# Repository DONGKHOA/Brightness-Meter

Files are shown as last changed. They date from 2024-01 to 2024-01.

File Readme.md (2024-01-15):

# BRIGHTNESS METER
## Yêu cầu hệ thống
- Thiết kế máy đo độ rọi ánh sáng sử dụng LDR: có 2 thang đo
  - Thang 1: tầm đo 10-100lux, độ phân giải 1lux
  - Thang 2: tầm đo 10-1000lux, độ phân giải 10lux
  - Màn hình hiển thị LCD giá trị đo được, có nút nhấn để thay đổi giữa 2 thang đo
  - Mạch cho phép cài đặt giá trị ngưỡng độ rọi thông qua LCD và nút nhấn. Nếu độ rọi đặt vào máy đo lớn hơn giá trị cài đặt, báo đỏ LED.

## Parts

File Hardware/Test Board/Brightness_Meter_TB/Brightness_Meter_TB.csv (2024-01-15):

Reference | Value | URL | Qty
-5V_LED1 | BLUE | https://www.thegioiic.com/led-xanh-duong-0805-dan-smd-trong-suot-harvatek | 1
3.3V1 | RED | https://www.thegioiic.com/led-xanh-duong-0805-dan-smd-trong-suot-harvatek | 1
BZ1 | Buzzer |  | 1
C1 | 22uF/25V | https://www.thegioiic.com/tu-nhom-smd-22uf-25v-6-3x5-4mm | 1
C2, C3 | 10uF/16V | https://www.thegioiic.com/tu-tantalum-10uf-16v-1206-taja106k016rnj | 2
C4, C11-C14, C16, C17, C19, C20, C22-C27 | 100nF/50V | https://www.thegioiic.com/tu-gom-0805-100nf-0-1uf-50v | 15
C5-C9, C18, C21 | 10uF/6.3V | https://www.thegioiic.com/tu-gom-0805-10uf-6-3v | 7
C10 | 10pF/50V | https://www.thegioiic.com/tu-gom-0805-10pf-50v | 1
C15 | 1uF/16V | https://www.thegioiic.com/tu-gom-0805-1uf-16v | 1
D1, D3 | SS34 | https://www.thegioiic.com/ss34-sma-diode-schottky-3a | 2
D2 | ZMM3V3 | https://www.thegioiic.com/zmm3v3-diode-zener-3-3v-500mw-smd | 1
D4 | ZMM5V1 | https://www.thegioiic.com/zmm5v1-diode-zener-5-1v-500mw-smd | 1
F1 | Fuse_Small |  | 1
J1 | JACK-DC | https://www.thegioiic.com/dc050-dau-noi-nguon-dc-cai-5521-dan-smd-kim-2-1mm | 1
Q1 | MMBT2222A |  | 1
Q2-Q5 | BSN20 | https://www.thegioiic.com/bsn20bkr-mosfet-kenh-n-50v-173ma-sot-23 | 4
R1, R2 | 4.7k/1% | https://www.thegioiic.com/dien-tro-4-7-kohm-0805-1- | 2
R3, R5-R8 | R_Small_US |  | 5
R4 | EVM-3ESX50B14 |  | 1
R9, R13 | EVM-3E |  | 2
R10, R11 | 0/1% | https://www.thegioiic.com/dien-tro-0-ohm-0805-1- | 2
R12 | GL5528 | https://www.thegioiic.com/gl5528-quang-tro-5mm | 1
R14 | 220/1% | https://www.thegioiic.com/dien-tro-220-ohm-0805-1- | 1
R15-R20, R23-R30 | 10k/1% | https://www.thegioiic.com/dien-tro-10-kohm-0805-1- | 14
R21, R22 | 1k/1% | https://www.thegioiic.com/dien-tro-1-kohm-0805-1- | 2
SW1 | UP | https://www.thegioiic.com/b3f-4055-nut-nhan-12x12mm-cao-7-3mm-4-chan-xuyen-lo-omron | 1
SW2 | DOWN | https://www.thegioiic.com/b3f-4055-nut-nhan-12x12mm-cao-7-3mm-4-chan-xuyen-lo-omron | 1
SW3 | LEFT | https://www.thegioiic.com/b3f-4055-nut-nhan-12x12mm-cao-7-3mm-4-chan-xuyen-lo-omron | 1
SW4 | RIGHT | https://www.thegioiic.com/b3f-4055-nut-nhan-12x12mm-cao-7-3mm-4-chan-xuyen-lo-omron | 1
SW5 | SET | https://www.thegioiic.com/b3f-4055-nut-nhan-12x12mm-cao-7-3mm-4-chan-xuyen-lo-omron | 1
SW6 | MODE | https://www.thegioiic.com/b3f-4055-nut-nhan-12x12mm-cao-7-3mm-4-chan-xuyen-lo-omron | 1
U1 | ICL7662CPA | https://www.thegioiic.com/icl7662cba | 1
U2 | STM32F103C8T6 |  | 1
U3 | MCP6002 | https://www.thegioiic.com/mcp6002-i-sn-ic-opamp-general-purpose-amplifier-2-circuit-1mhz-8-soic | 1
U4 | INA128 | https://tme.vn/Product.aspx?id=1612#page=pro_info | 1
U5 | HX710B | https://www.thegioiic.com/hx710b-ic-adc-24-bit-sop-8 | 1
U6 | SSD1306 | https://www.thegioiic.com/lcd-oled-ssd1306-0-96inch-128x64-chu-trang-4-chan-giao-tiep-iic | 1
Vin_LED1 | BLUE | https://www.thegioiic.com/led-xanh-duong-0805-dan-smd-trong-suot-harvatek | 1

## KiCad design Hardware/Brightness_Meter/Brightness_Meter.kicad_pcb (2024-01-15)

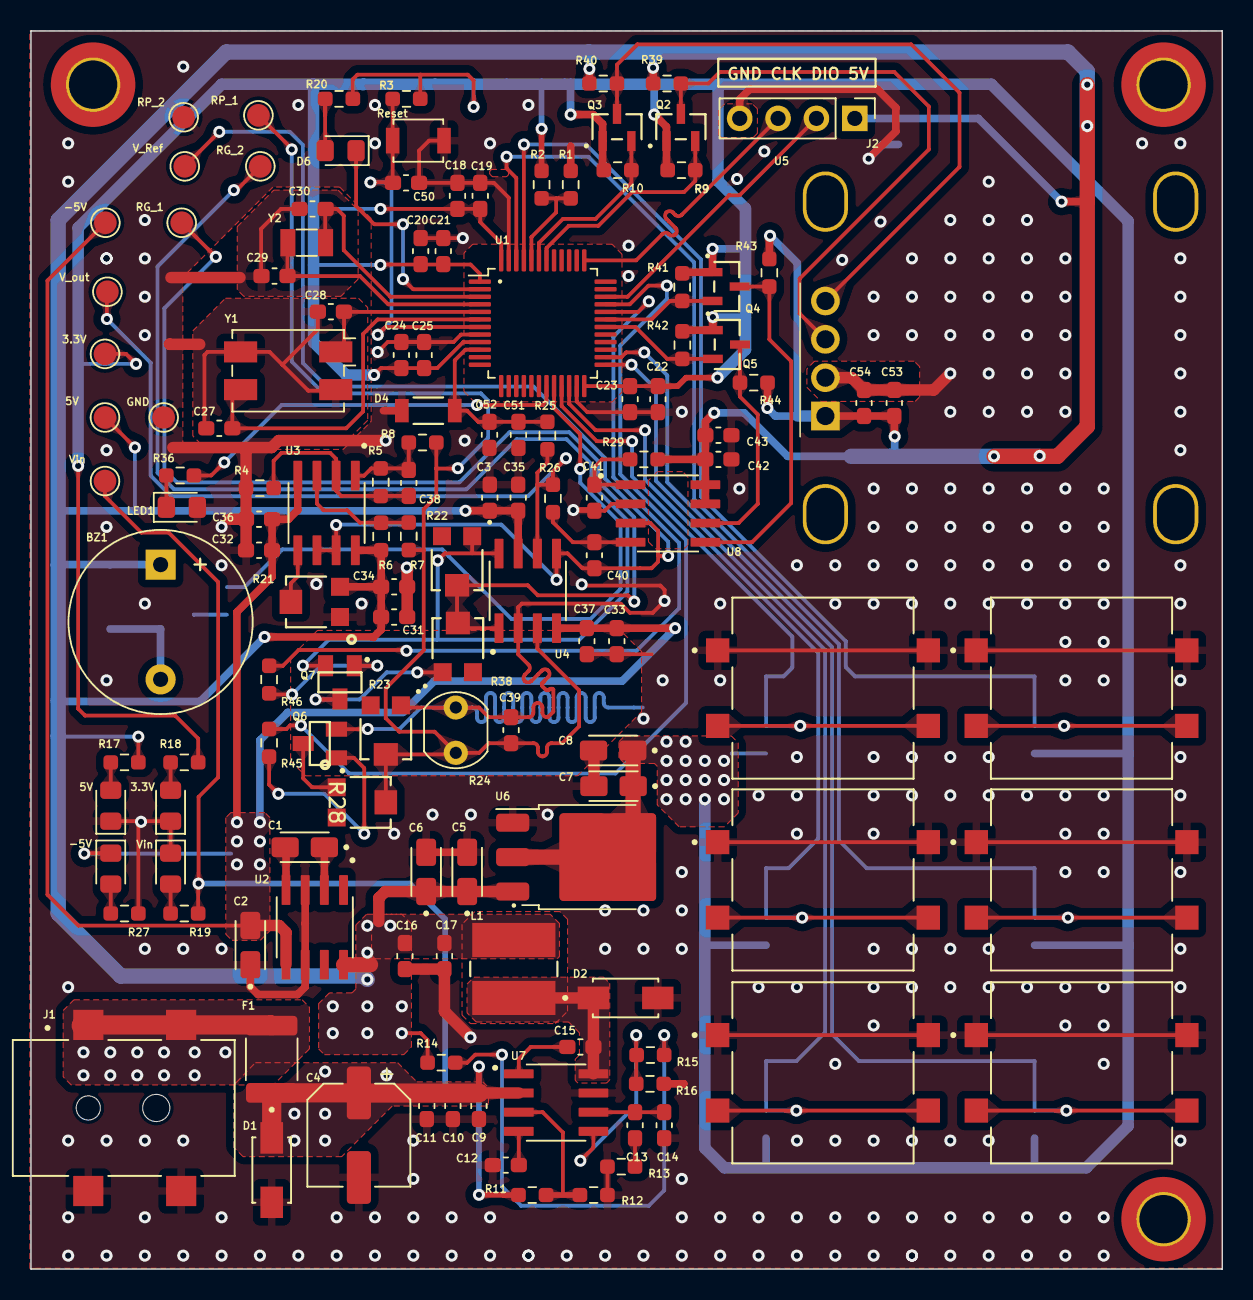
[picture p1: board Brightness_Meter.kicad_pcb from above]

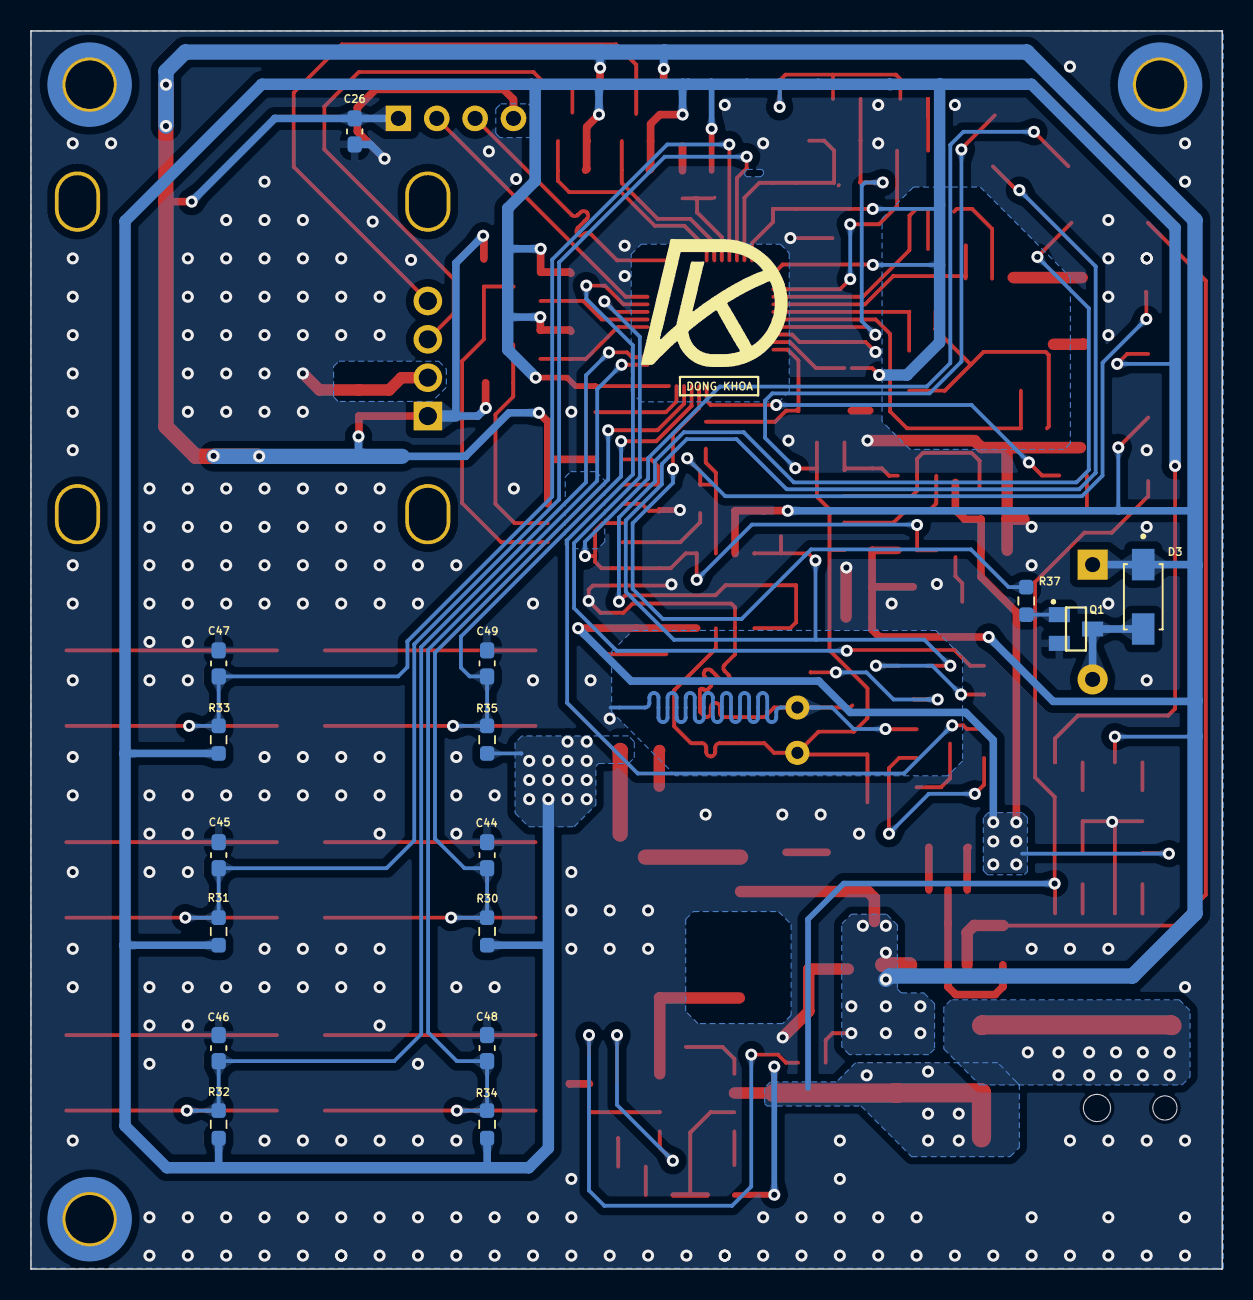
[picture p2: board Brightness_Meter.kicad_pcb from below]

Board: 2 copper layers, 78.9 x 82.0 mm, 153 parts (16 on the bottom side), 67 nets.

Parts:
3.3V: 3.3V; TestPoint_Pad_D1.5mm
3.3V#2, 5V#2: BLUE; LED_0805_2012Metric_Pad1.15x1.40mm_HandSolder
5V: 5V; TestPoint_Pad_D1.5mm
-5V: -5V; TestPoint_Pad_D1.5mm
-5V#2: BLUE; LED_0805_2012Metric_Pad1.15x1.40mm_HandSolder
BZ1: Buzzer; Buzzer_12x9.5RM7.6
C1, C2, C6, C7: 10uF/16V; CAPMP3216X180N
C3, C26, C31, C32, C33, C51: 10uF/16V; C_0603_1608Metric_Pad1.08x0.95mm_HandSolder
C4: 22uF/25V; CP_Elec_6.3x5.4
C5, C8: 1uF/25V; CAPMP3216X180N
C9, C10: 4.7uF/25V; C_0603_1608Metric_Pad1.08x0.95mm_HandSolder
C11, C12, C25: 10nF/50V; C_0603_1608Metric_Pad1.08x0.95mm_HandSolder
C13: 1nF/50V; C_0603_1608Metric_Pad1.08x0.95mm_HandSolder
C14: 47pF/50V; C_0603_1608Metric_Pad1.08x0.95mm_HandSolder
C15: 0.1uF/16V; C_0603_1608Metric_Pad1.08x0.95mm_HandSolder
C16, C17: 47uF/6.3V; C_0603_1608Metric_Pad1.08x0.95mm_HandSolder
C18, C20, C22: 4.7uF/10V; C_0603_1608Metric_Pad1.08x0.95mm_HandSolder
C19, C21, C23, C34, C35, C36, C37, C44, C45, C46, C47, C48, C49, C50, C52: 100nF/16V; C_0603_1608Metric_Pad1.08x0.95mm_HandSolder
C24, C39: 1uF/16V; C_0603_1608Metric_Pad1.08x0.95mm_HandSolder
C27, C28, C29, C30: 20pF/50V; C_0603_1608Metric_Pad1.08x0.95mm_HandSolder
C38: 10pF/50V; C_0603_1608Metric_Pad1.08x0.95mm_HandSolder
C40, C41, C43, C54: 100nF/50V; C_0603_1608Metric_Pad1.08x0.95mm_HandSolder
C42, C53: 10uF/6.3V; C_0603_1608Metric_Pad1.08x0.95mm_HandSolder
D1, D2, D3: SS34; DIOM4325X250N
D4: ZMM3V3; ZDO_ZMM_3p5x1p45_STM
D6: Led_test; LED_0805_2012Metric_Pad1.15x1.40mm_HandSolder
DOWN1: DOWN; SW_TL3300CF260Q
F1: Fuse_Small; Fuse_1812_4532Metric_Pad1.30x3.40mm_HandSolder
GND: GND; TestPoint_Pad_D1.5mm
H1, H2, H3: MountingHole; MountingHole_3.2mm_M3_DIN965_Pad_TopBottom
J1: JACK-DC; SPARKFUN_PRT-12748
J2: Load Program; PinHeader_1x04_P2.54mm_Vertical
L1: 6.8uH/2.2A; IND_SDE0604A_5P8X5P2X4P5_BRN
LED1: RED; LED_0805_2012Metric_Pad1.15x1.40mm_HandSolder
LEFT1: LEFT; SW_TL3300CF260Q
MODE1: MODE; SW_TL3300CF260Q
Q1, Q6, Q7: MMBT2222A; SOT23
Q2, Q3, Q4, Q5: BSN20; SOT23_NEX
R1, R2, R25, R26: 0/1%; R_0603_1608Metric_Pad0.98x0.95mm_HandSolder
R3, R9, R10, R16, R30, R31, R32, R33, R34, R35, R39, R40, R41, R42, R43, R44: 10k/1%; R_0603_1608Metric_Pad0.98x0.95mm_HandSolder
R4, R5, R6, R7, R8: R_Small_US; R_0603_1608Metric_Pad0.98x0.95mm_HandSolder
R11: 330k/1%; R_0603_1608Metric_Pad0.98x0.95mm_HandSolder
R12: 47k/1%; R_0603_1608Metric_Pad0.98x0.95mm_HandSolder
R13: 30k/1%; R_0603_1608Metric_Pad0.98x0.95mm_HandSolder
R14: 2.49k/1%; R_0603_1608Metric_Pad0.98x0.95mm_HandSolder
R15: 49.9k/1%; R_0603_1608Metric_Pad0.98x0.95mm_HandSolder
R17, R18, R20, R36, R37, R45, R46: 1k/1%; R_0603_1608Metric_Pad0.98x0.95mm_HandSolder
R19, R27: 4.7k/1%; R_0603_1608Metric_Pad0.98x0.95mm_HandSolder
R21: EVM-3ESX50B14; EVM-3ESX50B14_PAN
R22, R23, R28, R38: EVM-3E; EVM-3ESX50B14_PAN
R24: GL5528; R_LDR_5.0x4.1mm_P3mm_Vertical
R29: 220/1%; R_0603_1608Metric_Pad0.98x0.95mm_HandSolder
RG_1, RG_2: RG; TestPoint_Pad_D1.5mm
RIGHT1: RIGHT; SW_TL3300CF260Q
RP_1, RP_2: RP; TestPoint_Pad_D1.5mm
Reset: SW_Push; SW_SPST_B3U-1000P
SET1: SET; SW_TL3300CF260Q
U1: STM32F030C8Tx; LQFP-48_7x7mm_P0.5mm
U2: ICL7662CPA; SOIC127P600X175-8N
U3: MCP6002; SOIC127P599X173-8N
U4: INA128; SOIC127P599X175-8N
U5: SSD1306
U6: LM1117DT-3.3; TO-252-3_TabPin2
U7: TPS54331D; SOIC127P599X175-8N
U8: HX710B
UP1: UP; SW_TL3300CF260Q
V_Ref: V_Ref; TestPoint_Pad_D1.5mm
V_out: V_out; TestPoint_Pad_D1.5mm
Vin: BLUE; LED_0805_2012Metric_Pad1.15x1.40mm_HandSolder
Vin#2: Vin; TestPoint_Pad_D1.5mm
Y1: 8MHz; Crystal_SMD_EuroQuartz_MQ-4Pin_7.0x5.0mm
Y2: 32.768KHz; Crystal_SMD_3215-2Pin_3.2x1.5mm

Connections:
+3.3V: 3.3V.1, C7.1, C8.1, C18.1, C19.1, C20.1, C21.1, C22.1, C23.1, C24.1, C25.1, Q2.1 (G), Q3.1 (G), Q4.1 (G), Q5.1 (G), R2.1, R3.1, R9.1, R10.1, R18.1, R20.1, R30.2, R31.2, R32.2, R33.2, R34.2, R35.2, R41.1, R42.1, U1.1 (VDD), U1.9 (VDDA), U1.24 (VDD), U1.48 (VDD), U6.2 (VO)
+5V: 5V.1, BZ1.1 (-), C3.1, C5.1, C6.1, C16.1, C17.1, C26.1, C31.1, C34.1, C35.1, C42.1, C43.1, C53.1, C54.1, D3.C, J2.1, L1.1, R6.2, R14.1, R17.1, R21.3, R29.2, R39.1, R40.1, R43.1, R44.1, U2.8 (V+), U3.8 (VDD), U4.7 (V+), U5.1 (vcc), U6.3 (VI), U8.7 (DVDD), U8.8 (AVDD)
-5V: -5V.1, -5V#2.1 (K), C2.2, C32.2, C33.2, C36.2, C37.2, U2.5 (VOUT), U3.4 (VSS), U4.4 (V-)
/MCU/BOOT0: R1.1, R2.2, U1.44 (BOOT0)
/MCU/LED_TEST: D6.1 (K), U1.2 (PC13)
/MCU/OSC32_IN: C30.1, U1.3 (PC14), Y2.1
/MCU/OSC32_OUT: C29.1, U1.4 (PC15), Y2.2
/MCU/OSC_IN: C28.1, U1.5 (PF0), Y1.1
/MCU/OSC_OUT: C27.1, U1.6 (PF1), Y1.3
/MCU/RESET: C50.2, R3.2, Reset.2, U1.7 (NRST)
/MCU/SWCLK: J2.3, U1.37 (PA14)
/MCU/SWDIO: J2.2, U1.34 (PA13)
/Power/Vin: C4.1, C9.1, C10.1, C11.1, D1.C, F1.2, R11.1, R19.1, U7.2 (VIN), Vin#2.1
/measure/CURRENT_SRC: C39.2, R7.1, R8.2, R23.2, R24.1, R28.2, RP_1.1, U4.3 (+)
/measure/vout: R25.2, R26.1, U4.6, V_out.1
ADC_CLK: Q4.2 (S), R41.2, U1.31 (PA10)
ADC_DATA: Q5.2 (S), R42.2, U1.30 (PA9)
ADC_HX71OB: C40.2, R26.2, U8.4 (INP)
ADC_INO: C51.1, C52.1, D4.1, R25.1, U1.10 (PA0)
BUZZER: R37.1, U1.20 (PB2)
CHANGE_GAIN: R46.2, U1.32 (PA11)
CHANGE_RESISTOR: R45.2, U1.33 (PA12)
CLK_HX710B: Q4.3 (D), R43.2, U8.5 (PD_SCK)
DATA_HX710B: Q5.3 (D), R44.2, U8.6 (DOUT)
GND: 3.3V#2.1 (K), 5V#2.1 (K), C2.1, C3.2, C4.2, C5.2, C6.2, C7.2, C8.2, C9.2, C10.2, C11.2, C12.2, C14.2, C16.2, C17.2, C18.2, C19.2, C20.2, C21.2, C22.2, C23.2, C24.2, C25.2, C26.2, C27.2, C28.2, C29.2, C30.2, C31.2, C32.1, C33.1, C34.2, C35.2, C36.1, C37.1, C39.1, C41.1, C42.2, C43.2, C44.1, C45.1, C46.1, C47.1, C48.1, C49.1, C50.1, C51.2, C52.2, C53.2, C54.2, D1.A, D2.A, D4.2, DOWN1.1, DOWN1.2, GND.1, J1.2, J1.3, J2.4, LED1.2 (A), LEFT1.1, LEFT1.2, MODE1.1, MODE1.2, Q1.2, Q6.2, R1.2, R4.2, R12.2, R13.2, R16.2, R21.1, R23.1, R24.2, R27.2, RIGHT1.1, RIGHT1.2, RP_2.1, Reset.1, SET1.1, SET1.2, U1.8 (VSSA), U1.23 (VSS), U1.47 (VSS), U2.3 (GND), U2.6 (LV), U4.2 (-), U5.2 (gnd), U6.1 (GND), U7.7 (GND), U8.2 (AGND), UP1.1, UP1.2, Vin.1 (K), Y1.2, Y1.4
I2C_SCL: Q2.2 (S), R9.2, U1.42 (PB6)
I2C_SDA: Q3.2 (S), R10.2, U1.43 (PB7)
LED_INFO: R36.2, U1.19 (PB1)
unnamed: 3.3V#2.2 (A), R18.2
unnamed: 5V#2.2 (A), R17.2
unnamed: -5V#2.2 (A), R27.1
unnamed: BZ1.2 (+), D3.A, Q1.3
unnamed: C13.2, R13.1
unnamed: D6.2 (A), R20.2
unnamed: F1.1, J1.1_1, J1.1_2
unnamed: LED1.1 (K), R36.1
unnamed: Q1.1, R37.2
unnamed: Q6.1, R45.1
unnamed: Q6.3, R28.1
unnamed: Q7.1, R46.1
unnamed: Q7.2, R22.1, RG_2.1, U4.8 (Rg)
unnamed: Q7.3, R38.1
unnamed: R14.2, R15.1
unnamed: R22.2, R38.2, RG_1.1, U4.1 (Rg)
unnamed: C1.1, U2.2 (CAP+)
unnamed: C1.2, U2.4 (CAP-)
unnamed: R6.1, R7.2, U3.3 (VINA+)
unnamed: C38.1, R4.1, R5.2, U3.2 (VINA-)
unnamed: R21.2, U3.5 (VINB+)
unnamed: C38.2, R5.1, R8.1, U3.1 (VOUTA)
unnamed: C15.2, U7.1 (BOOT)
unnamed: C13.1, C14.1, U7.6 (COMP)
unnamed: R11.2, R12.1, U7.3 (EN)
unnamed: C15.1, D2.C, L1.2, U7.8 (PH)
unnamed: C12.1, U7.4 (SS)
unnamed: R15.2, R16.1, U7.5 (VSENSE)
unnamed: C41.2, R29.1, U8.1 (VREF)
unnamed: R19.2, Vin.2 (A)
SCL_SSD1306: Q2.3 (D), R39.2, U5.3 (scl)
SDA_SSD1306: Q3.3 (D), R40.2, U5.4 (sda)
SW_DOWN: C45.2, DOWN1.3, DOWN1.4, R31.1, U1.46 (PB9)
SW_LEFT: C46.2, LEFT1.3, LEFT1.4, R32.1, U1.26 (PB13)
SW_MODE: C49.2, MODE1.3, MODE1.4, R35.1, U1.21 (PB10)
SW_RIGHT: C47.2, R33.1, RIGHT1.3, RIGHT1.4, U1.45 (PB8)
SW_SET: C48.2, R34.1, SET1.3, SET1.4, U1.25 (PB12)
SW_UP: C44.2, R30.1, U1.22 (PB11), UP1.3, UP1.4
VREF: C40.1, U3.6 (VINB-), U3.7 (VOUTB), U4.5 (Ref), U8.3 (INN), V_Ref.1

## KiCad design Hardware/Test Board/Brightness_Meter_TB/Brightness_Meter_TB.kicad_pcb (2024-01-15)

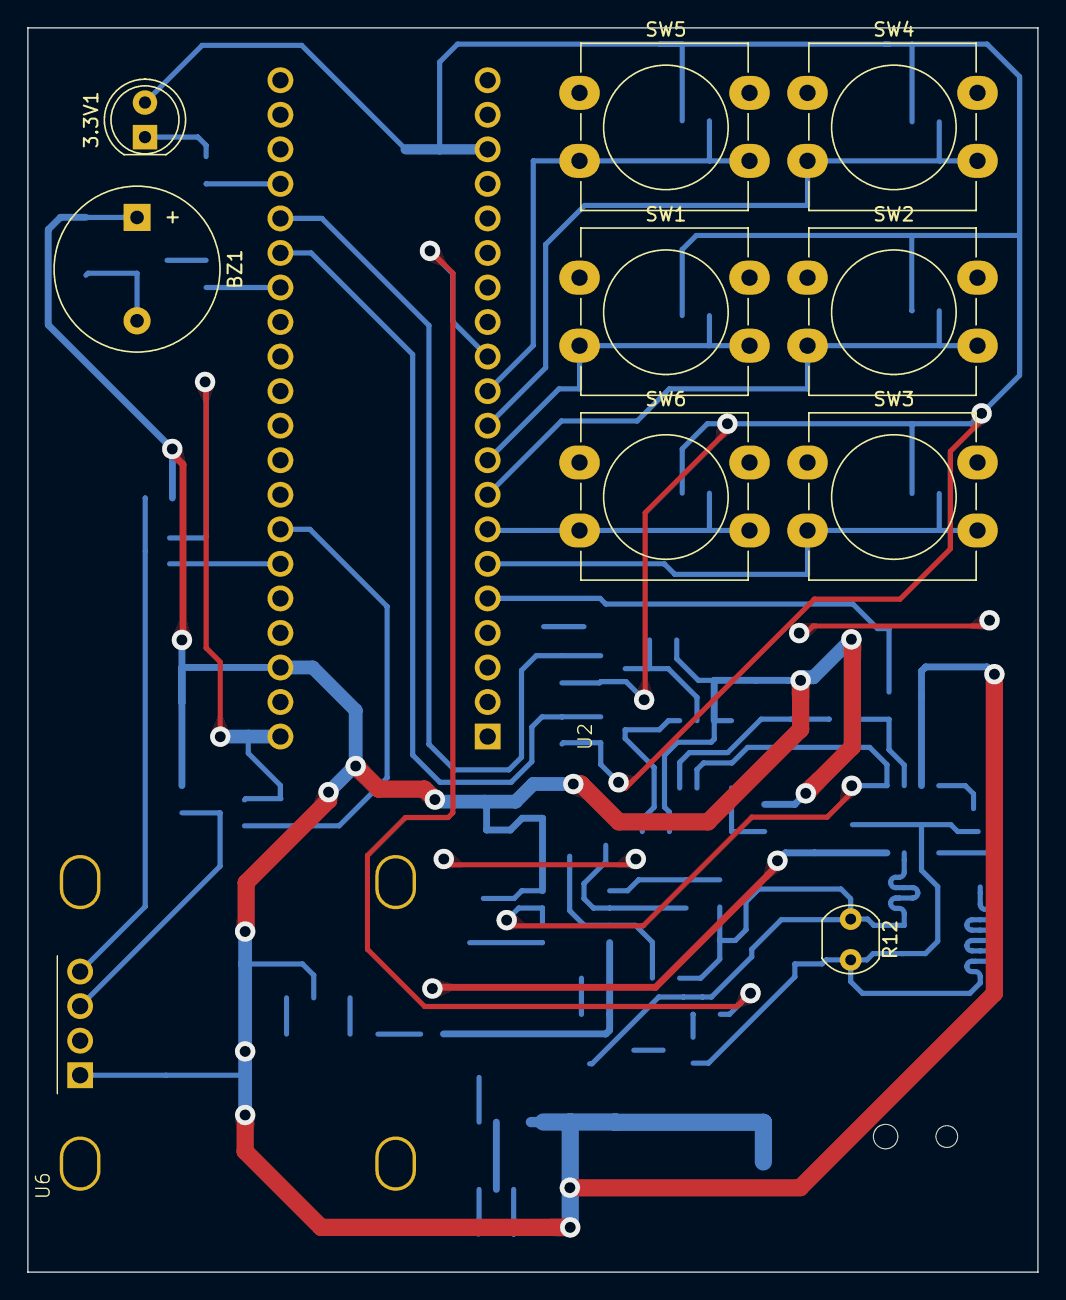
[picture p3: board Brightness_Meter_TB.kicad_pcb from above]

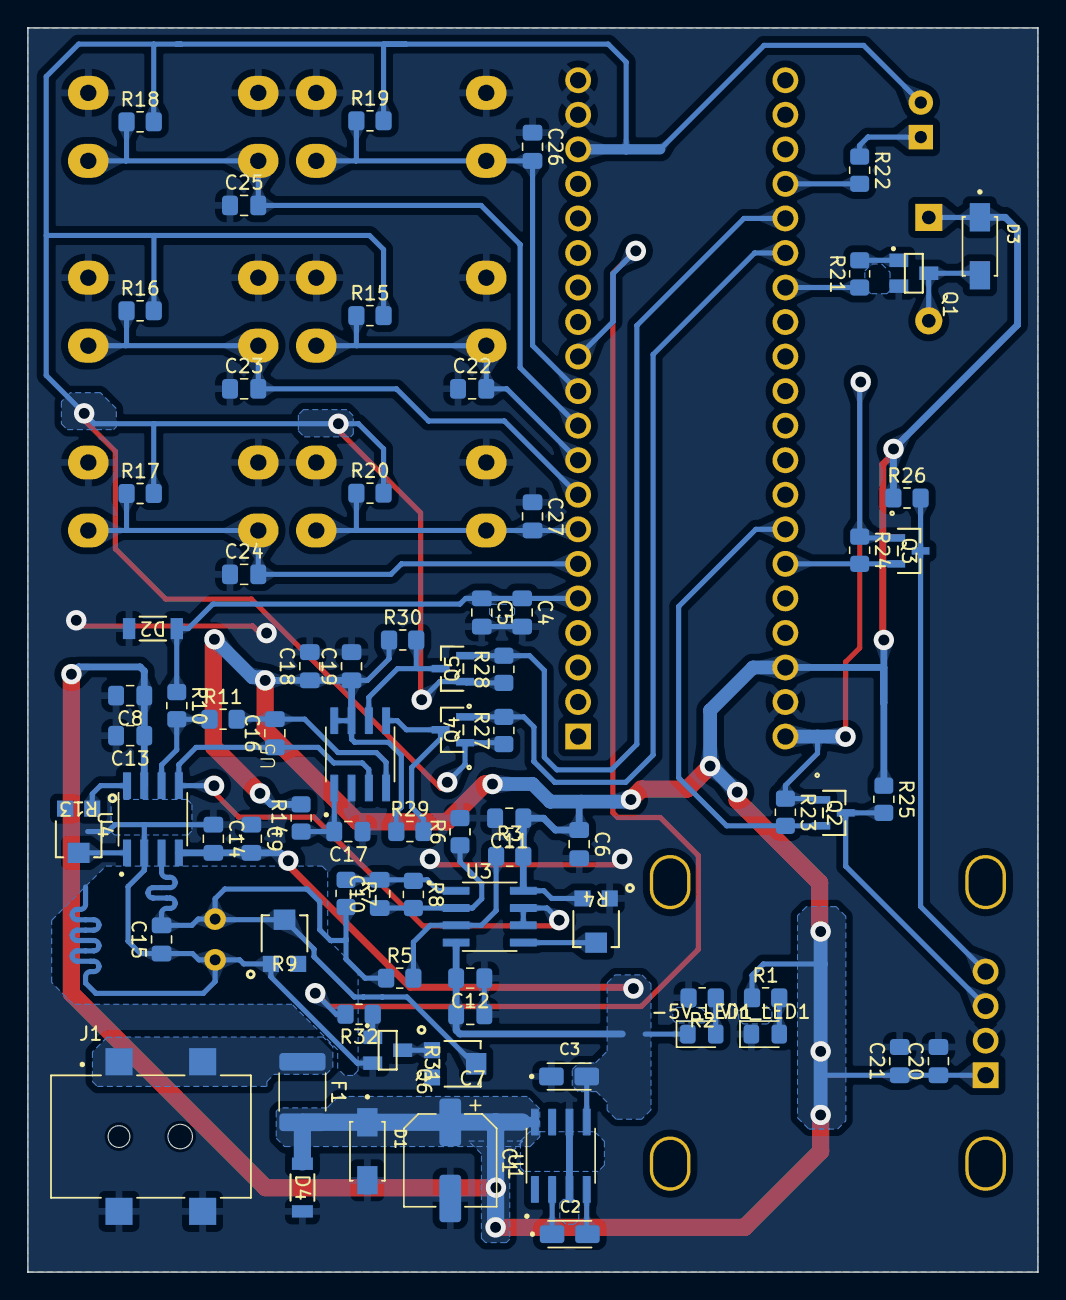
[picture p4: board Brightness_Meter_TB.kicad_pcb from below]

Board: 2 copper layers, 74.3 x 91.5 mm, 87 parts (76 on the bottom side), 43 nets.

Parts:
3.3V1: RED; LED_D5.0mm
-5V_LED1: BLUE; LED_0805_2012Metric_Pad1.15x1.40mm_HandSolder
BZ1: Buzzer; Buzzer_12x9.5RM7.6
C1: 22uF/25V; CP_Elec_6.3x5.4
C2, C3: 10uF/16V; CAPMP3216X180N
C4, C11, C12, C13, C14, C16, C17, C19, C20, C22, C23, C24, C25, C26, C27: 100nF/50V; C_0805_2012Metric_Pad1.18x1.45mm_HandSolder
C5, C6, C7, C8, C9, C18, C21: 10uF/6.3V; C_0805_2012Metric_Pad1.18x1.45mm_HandSolder
C10: 10pF/50V; C_0805_2012Metric_Pad1.18x1.45mm_HandSolder
C15: 1uF/16V; C_0805_2012Metric_Pad1.18x1.45mm_HandSolder
D1, D3: SS34; DIOM4325X250N
D2: ZMM3V3; ZDO_ZMM_3p5x1p45_STM
D4: ZMM5V1; ZDO_ZMM_3p5x1p45_STM
F1: Fuse_Small; Fuse_1812_4532Metric_Pad1.30x3.40mm_HandSolder
J1: JACK-DC; SPARKFUN_PRT-12748
Q1, Q6: MMBT2222A; SOT23
Q2, Q3, Q4, Q5: BSN20; SOT23_NEX
R1, R2: 4.7k/1%; R_0805_2012Metric_Pad1.20x1.40mm_HandSolder
R3, R5, R6, R7, R8: R_Small_US; R_0805_2012Metric_Pad1.20x1.40mm_HandSolder
R4: EVM-3ESX50B14; EVM-3ESX50B14_PAN
R9, R13, R31: EVM-3E; EVM-3ESX50B14_PAN
R10, R11: 0/1%; R_0805_2012Metric_Pad1.20x1.40mm_HandSolder
R12: GL5528; R_LDR_5.0x4.1mm_P3mm_Vertical
R14: 220/1%; R_0805_2012Metric_Pad1.20x1.40mm_HandSolder
R15, R16, R17, R18, R19, R20, R23, R24, R25, R26, R27, R28, R29, R30: 10k/1%; R_0805_2012Metric_Pad1.20x1.40mm_HandSolder
R21, R22, R32: 1k/1%; R_0805_2012Metric_Pad1.20x1.40mm_HandSolder
SW1: UP; SW_PUSH-12mm_Wuerth-430476085716
SW2: DOWN; SW_PUSH-12mm_Wuerth-430476085716
SW3: LEFT; SW_PUSH-12mm_Wuerth-430476085716
SW4: RIGHT; SW_PUSH-12mm_Wuerth-430476085716
SW5: SET; SW_PUSH-12mm_Wuerth-430476085716
SW6: MODE; SW_PUSH-12mm_Wuerth-430476085716
U1: ICL7662CPA; SOIC127P600X175-8N
U2: STM32F103C8T6; STM32F103C8T6_BP
U3: MCP6002; SOIC127P599X173-8N
U4: INA128; SOIC127P599X175-8N
U5: HX710B
U6: SSD1306
Vin_LED1: BLUE; LED_0805_2012Metric_Pad1.15x1.40mm_HandSolder

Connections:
+3.3V: 3.3V1.2 (A), Q2.1 (G), Q3.1 (G), Q4.1 (G), Q5.1 (G), R15.2, R16.2, R17.2, R18.2, R19.2, R20.2, R23.1, R24.1, R27.1, R28.1, U2.1 (VBAT), U2.18 (3V3), U2.40 (3V3)
+5V: BZ1.1 (-), C1.1, C6.1, C8.1, C11.1, C13.1, C18.1, C19.1, C20.1, C21.1, D1.C, D3.C, D4.1, F1.2, R1.1, R3.2, R4.3, R14.2, R25.1, R26.1, R29.1, R30.1, U1.8 (V+), U2.38 (5V), U3.8 (VDD), U4.7 (V+), U5.7 (DVDD), U5.8 (AVDD), U6.1 (vcc)
-5V: -5V_LED1.1 (K), C3.2, C7.2, C9.2, C12.2, C14.2, U1.5 (VOUT), U3.4 (VSS), U4.4 (V-)
/Measure/CURRENT_SRC: C15.2, R5.1, R7.2, R9.2, R12.1, R31.2, U4.3 (+)
/Measure/vout: R10.2, R11.1, U4.6
ADC_CLK: Q4.2 (S), R27.2, U2.26 (PA9)
ADC_DATA: Q5.2 (S), R28.2, U2.25 (PA8)
ADC_HX71OB: C16.2, R11.2, U5.4 (INP)
ADC_INO: C4.1, C5.1, D2.1, R10.1, U2.5 (PA0)
BUZZER: R21.1, U2.27 (PA10)
CHANGE_RESISTOR: R32.2, U2.12 (PA7)
CLK_HX710B: Q4.3 (D), R29.2, U5.5 (PD_SCK)
DATA_HX710B: Q5.3 (D), R30.2, U5.6 (DOUT)
GND: C1.2, C3.1, C4.2, C5.2, C6.2, C7.1, C8.2, C9.1, C11.2, C12.1, C13.2, C14.1, C15.1, C17.1, C18.2, C19.2, C20.2, C21.2, C22.1, C23.1, C24.1, C25.1, C26.1, C27.1, D1.A, D2.2, D4.2, J1.2, J1.3, Q1.2, Q6.2, R2.2, R4.1, R6.2, R9.1, R12.2, SW1.1, SW2.1, SW3.1, SW4.1, SW5.1, SW6.1, U1.3 (GND), U1.6 (LV), U2.19 (GND), U2.20 (GND), U2.39 (GND), U4.2 (-), U5.2 (AGND), U6.2 (gnd), Vin_LED1.1 (K)
I2C_SCL: Q2.2 (S), R23.2, U2.34 (PB6)
I2C_SDA: Q3.2 (S), R24.2, U2.35 (PB7)
LED_INFO: R22.2, U2.24 (PB15)
unnamed: 3.3V1.1 (K), R22.1
unnamed: -5V_LED1.2 (A), R2.1
unnamed: BZ1.2 (+), D3.A, Q1.3
unnamed: F1.1, J1.1_1, J1.1_2
unnamed: Q1.1, R21.2
unnamed: Q6.1, R32.1
unnamed: Q6.3, R31.1
unnamed: R13.1, U4.8 (Rg)
unnamed: R13.2, U4.1 (Rg)
unnamed: C2.1, U1.2 (CAP+)
unnamed: C2.2, U1.4 (CAP-)
unnamed: R3.1, R5.2, U3.3 (VINA+)
unnamed: C10.1, R6.1, R8.2, U3.2 (VINA-)
unnamed: R4.2, U3.5 (VINB+)
unnamed: C10.2, R7.1, R8.1, U3.1 (VOUTA)
unnamed: C17.2, R14.1, U5.1 (VREF)
unnamed: R1.2, Vin_LED1.2 (A)
SCL_SSD1306: Q2.3 (D), R25.2, U6.3 (scl)
SDA_SSD1306: Q3.3 (D), R26.2, U6.4 (sda)
SW_DOWN: C23.2, R16.1, SW2.2, U2.8 (PA3)
SW_LEFT: C24.2, R17.1, SW3.2, U2.6 (PA1)
SW_MODE: C27.2, R20.1, SW6.2, U2.7 (PA2)
SW_RIGHT: C25.2, R18.1, SW4.2, U2.10 (PA5)
SW_SET: C26.2, R19.1, SW5.2, U2.11 (PA6)
SW_UP: C22.2, R15.1, SW1.2, U2.9 (PA4)
VREF: C16.1, U3.6 (VINB-), U3.7 (VOUTB), U4.5 (Ref), U5.3 (INN)

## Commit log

2023-12-06 upload folder
    [Brightness_Meter.kicad_pcb, Brightness_Meter.kicad_sch, lcd.kicad_sch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]
2024-01-15 upload hardware
    [Brightness_Meter.kicad_pcb, Brightness_Meter.kicad_sch, Brightness_Meter_TB.csv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]
